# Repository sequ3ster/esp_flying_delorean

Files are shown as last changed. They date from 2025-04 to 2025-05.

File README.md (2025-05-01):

# ESP Flying Delorean

[Circuit](/circuit)<br><br>
[Firmware Installation](/installation)<br><br>
[3D Printing STL](/stl) for EQ LED Mod<br><br>

## Wifi Controller for the Flying DELOREAN V2 Animatronic from Did3D.
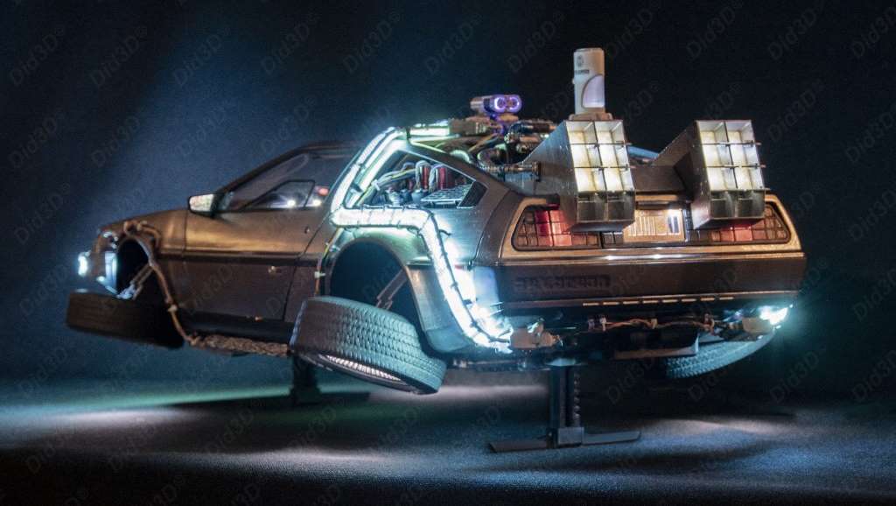
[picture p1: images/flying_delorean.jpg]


<br>[Didier Picard](https://www.did3d.fr) has created an impressive 3D model of a [flying Delorean from Back to the Future Part II](https://www.cgtrader.com/3d-print-models/miniatures/vehicles/flying-delorean-v2-hq-1-8-scale-530mm-3d-print-model).
This model has animatronic and can be controlled via a button on the bottom. The LEDs, servos and sound module are controlled by an Arduino Nano. As there is already a lot to control, all the outputs of the Arduino Nano are used. This leaves no room for expansion.

That's why I thought it would be a good idea to connect an ESP8266 to the Arduino. This way the Delorean can be switched on and off via Wifi and the scenes and moods can also be switched. In addition, there are enough free connections to add the EQ LED mod from the Delorean V1.<br><br>

**Functions**
- Wifi connection with website for control 
- Switching the Delorean on/off
- Changing the scenes
- Changing the mode
- Communication via MQTT (with Home Assistant Discovery Support)
- EQ LED mod for the status indicator<br>

$${\color{red}WARNING!}$$: The car must never be switched on unless it is resting on its wheels in road mode,
otherwise there is a risk of breaking the gears.
This is why the on/off button on the website and the mqtt power switch do not work when the Delorean is flying.
<br><br>

<br><br>**Frontend**
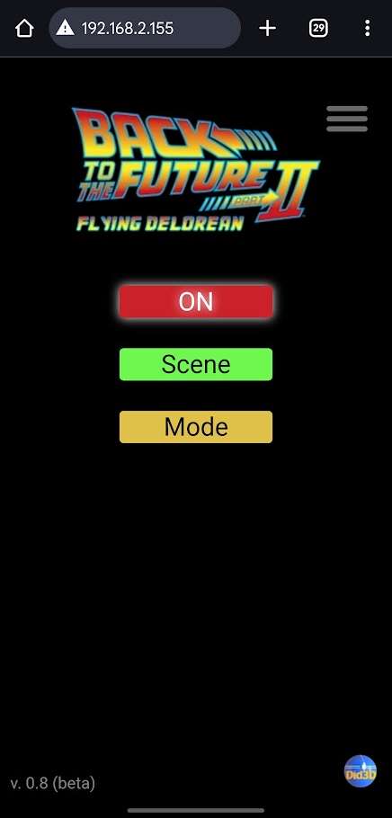
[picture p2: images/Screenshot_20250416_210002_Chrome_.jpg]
<br>
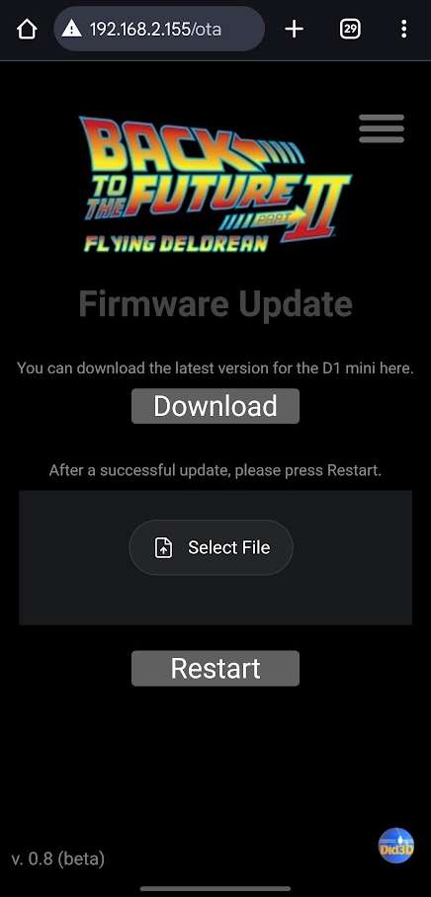
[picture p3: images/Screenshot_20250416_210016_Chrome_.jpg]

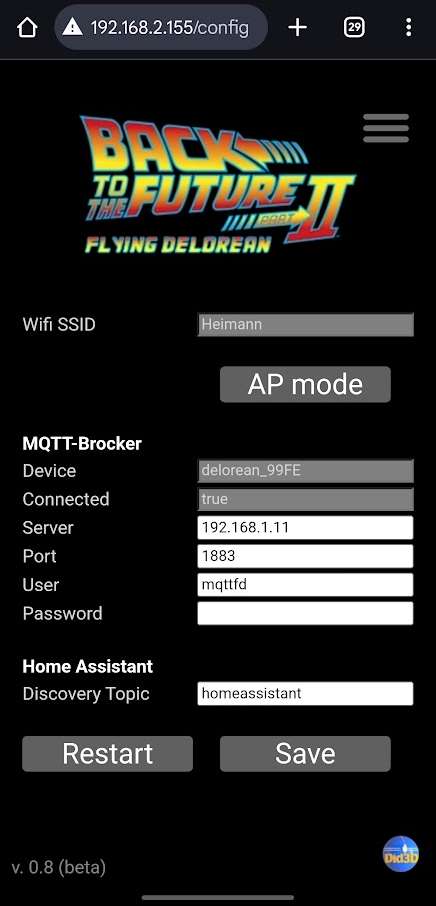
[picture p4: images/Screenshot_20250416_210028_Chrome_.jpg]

<br><br>

**Home Assistant**
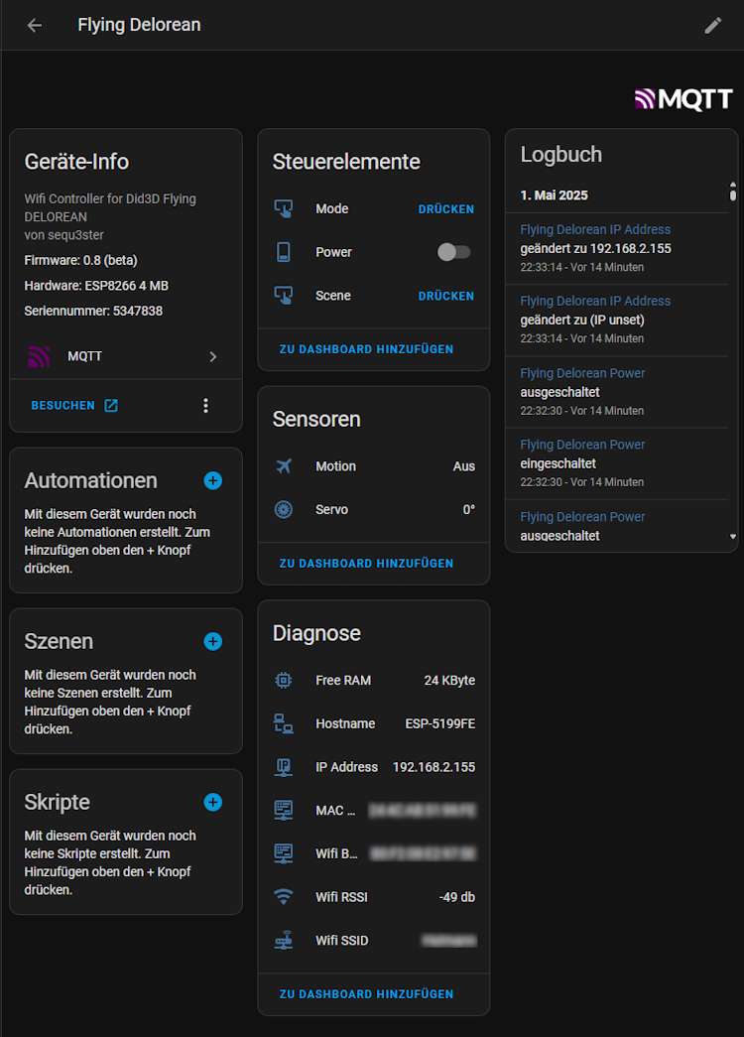
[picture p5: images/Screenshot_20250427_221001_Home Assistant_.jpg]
<br>
<br><br>

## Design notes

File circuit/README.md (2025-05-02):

# Circuit

<table>
  <tr><td><b>Parts</td><td><b>EQ LED Mod</td><td><b>Wifi Mod</td><td><b>Wifi and EQ LED</td></tr>
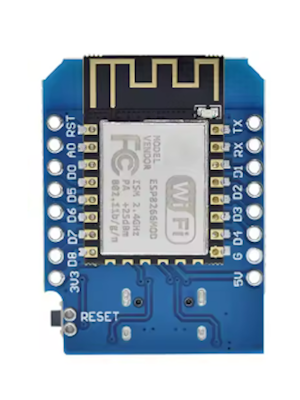
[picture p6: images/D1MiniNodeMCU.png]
  <tr><td><br><a href="https://de.aliexpress.com/item/1005006890254253.html">ES8266 D1 mini (Clone)</a></td><td>$${\color{green}✓}$$</td><td>$${\color{green}✓}$$</td><td>$${\color{green}✓}$$</td></tr>
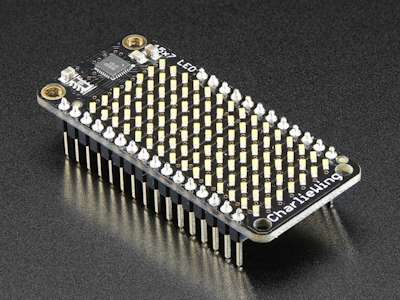
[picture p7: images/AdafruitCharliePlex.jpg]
  <tr><td><br><a href="https://www.berrybase.de/adafruit-15x7-charlieplex-led-matrix-featherwing-warmweiss">Adafruid 15x7 CharliPlex LED Matrix FeatherWing Warm White</a></td><td>$${\color{green}✓}$$</td><td></td><td>$${\color{green}✓}$$</td></tr>
  <tr><td><a href="https://aliexpress.com/item/1005006189547427.html">2x 1k ohm 1/4 watt Resistor</a></td><td></td><td>$${\color{green}✓}$$</td><td>$${\color{green}✓}$$</td></tr>
  <tr><td><a href="https://aliexpress.com/item/1005006189547427.html">2x 10k ohm 1/4 watt Resistor</a></td><td></td><td>$${\color{green}✓}$$</td><td>$${\color{green}✓}$$</td></tr>  
  <tr><td><a href="https://aliexpress.com/item/1005006189547427.html">1x 180k ohm 1/4 watt Resistor</a></td><td></td><td>$${\color{green}✓}$$</td><td>$${\color{green}✓}$$</td></tr>
  <tr><td><a href="https://aliexpress.com/item/1005006189547427.html">1x 220k ohm 1/4 watt Resistor</a></td><td></td><td>$${\color{green}✓}$$</td><td>$${\color{green}✓}$$</td></tr>    
  <tr><td><a href="https://aliexpress.com/item/1005007830470028.html">1x BC547C Transistor</a></td><td></td><td>$${\color{green}✓}$$</td><td>$${\color{green}✓}$$</td></tr>
  <tr><td><a href="https://aliexpress.com/item/33009989924.html">1x IRF9540 Mosfet</a></td><td></td><td>$${\color{green}✓}$$</td><td>$${\color{green}✓}$$</td></tr>
</table>
<br>
  
## EQ LED Mod only

For the EQ LED Mod you only need to connect the Adafruid CharlyPlex to 3.3V, GND, SDA and SCL from the D1 mini. Connect also A0 to 3.3V and RX to Ground. RX to Ground will deactivate Wifi. In that case, the D1 mini will not create an unsafe Access Point for configuration. 
Every time the Deloren is Power on, the CharlyPlex will start the LED Animation for the Status Indicator. This Mod need more room, therefore
you need another Wall-Rear for the Deloren. Also you need anoter EQ-Defusor and EQ-Front.
All STL Files you will find [here](/stl).
<br>$${\color{red}Attention!}$$ Remove RX from Ground for flashing Firmware.
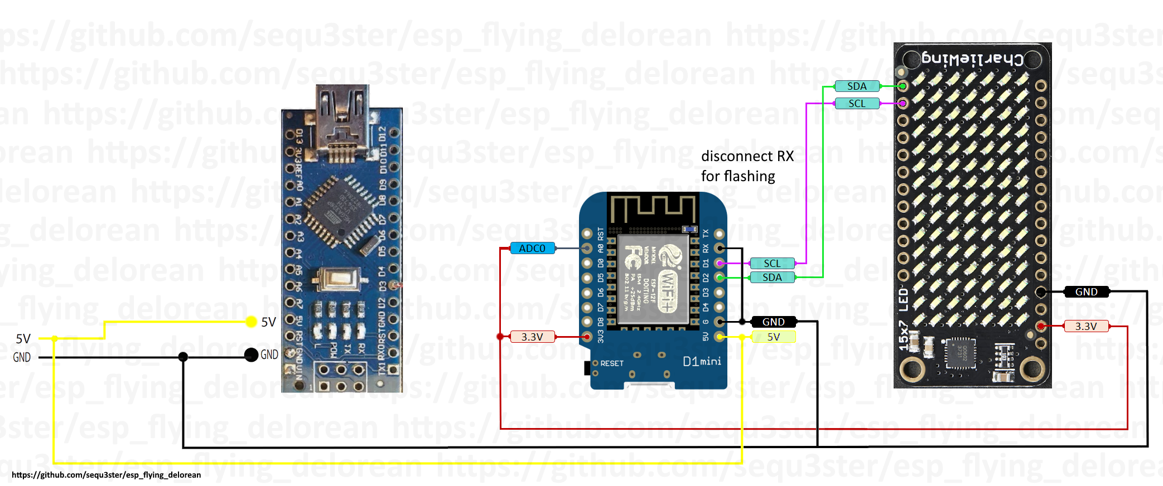
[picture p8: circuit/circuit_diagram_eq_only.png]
<br>
<br><br>

## Wifi Control only

The D1 Mini uses A1 (Ft Servo) to check whether the Delorean is flying. The connection to A6 simulates the push button and there we need a resistor to prevent a short circuit. The IRF9540 interrupts or releases the power to the Arduino. The D1 Mini is also connecte to the Drain from the Mosfet, to detect whether the Delorean is on or off. 
<br>$${\color{red}Attention!}$$ The Arduino uses a different voltage (5V) at the PINs than the D1 Mini (3.3V). Therefore we need another resistors for protection.
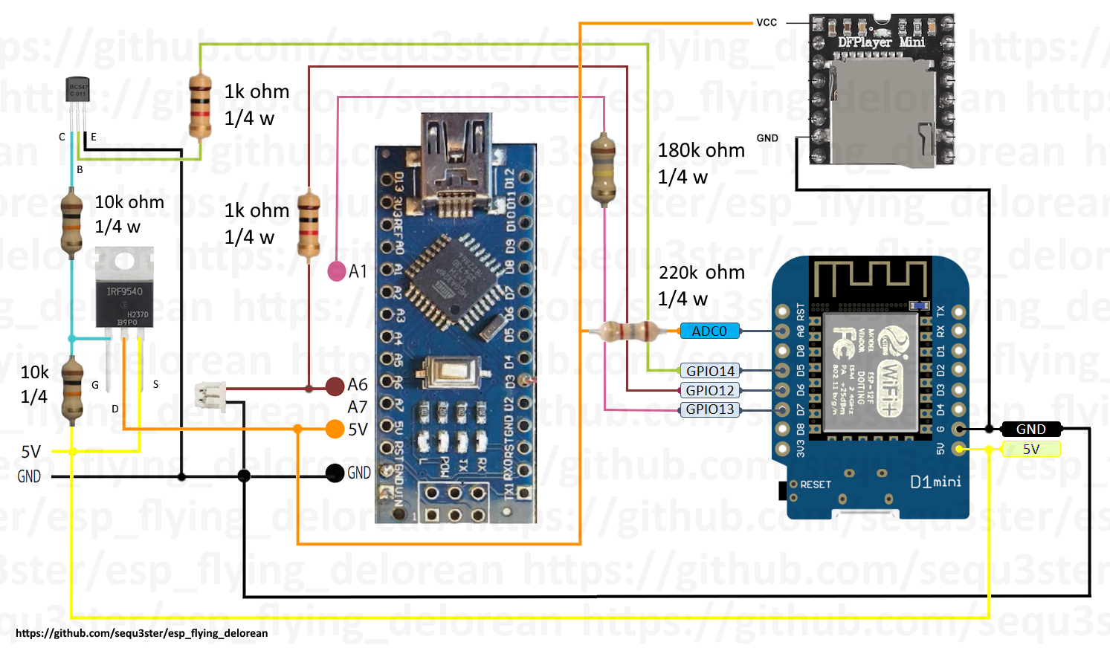
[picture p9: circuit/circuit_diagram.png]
<br>
<br><br>

## Wifi Control with EQ LED Mod

The same as with the two mods above. Except that A0 is not connected to 3.3V, but to the drain of the mosfet. 
<br>$${\color{red}Attention!}$$ RX remains open and is not connected to ground. Because RX to Ground will deactivate Wifi.
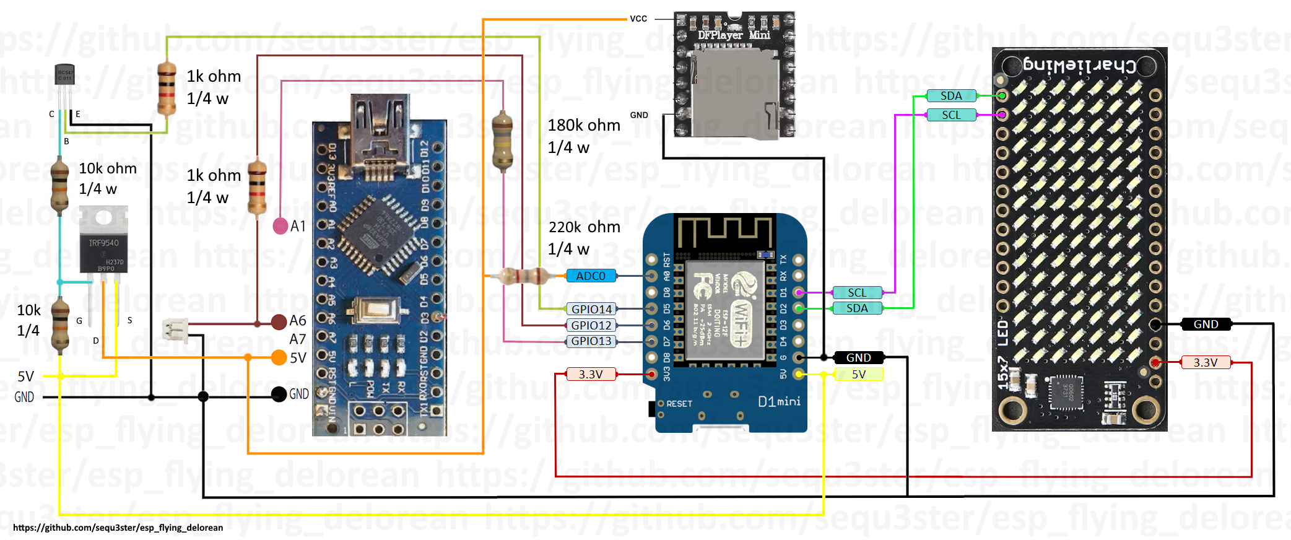
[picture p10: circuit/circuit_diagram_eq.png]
<br>
<br><br>

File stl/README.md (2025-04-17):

## 3D Printing

You need to print the [Wall rear](/stl/Wall_Rear_EQ_version_large_hall_V2.stl), [EQ Front](/stl/EQ-front.stl) and one of the "EQ defuser".  
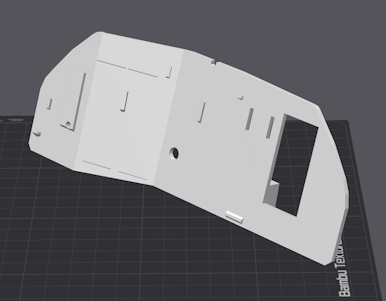
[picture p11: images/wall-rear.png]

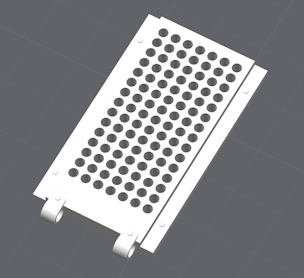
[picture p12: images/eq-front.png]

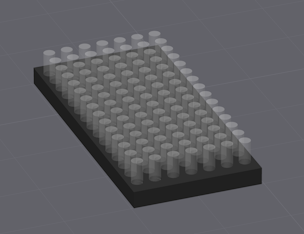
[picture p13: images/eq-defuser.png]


**[EQ-defuser.stl](/stl/EQ-defuser.stl)**<br>
You need to print 7 times this EQ-defuser.
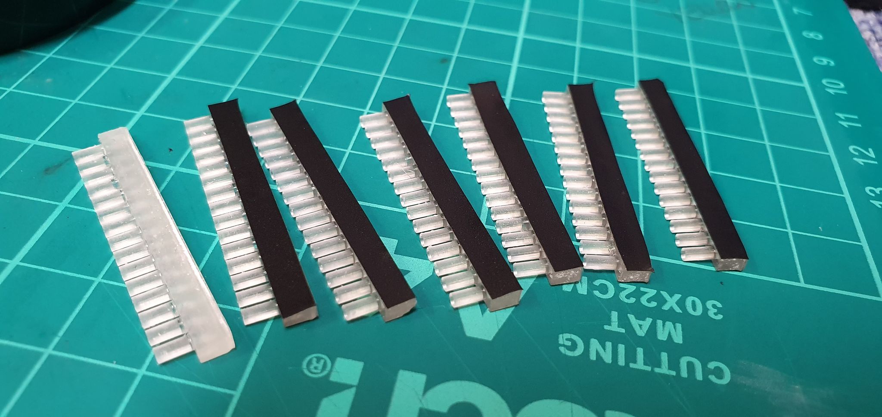
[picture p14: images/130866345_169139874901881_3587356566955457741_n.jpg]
<br>

**[EQ-defuser-ams.stl](/stl/EQ-defuser-ams.stl)**<br>
Or you print this EQ-defuser with a Multicolor FDM Printer like Bambu Lab.
In this version, each LED has its own defuser. These are then separated by a different Filament Color.<br>
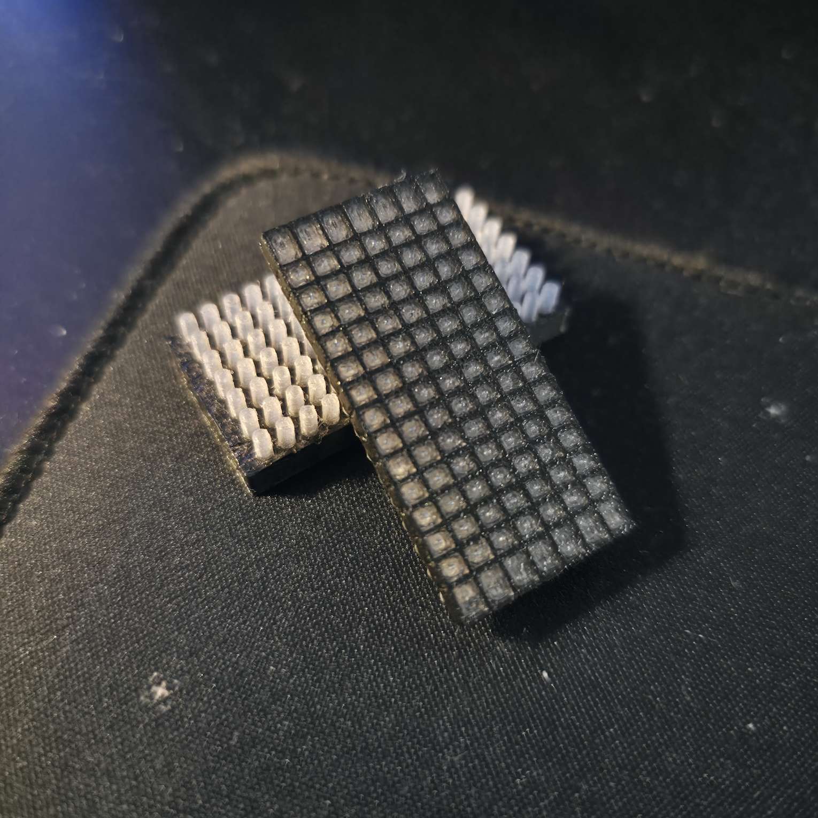
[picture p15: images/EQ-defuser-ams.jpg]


**[EQ-Mod.3mf](/stl/EQ-Mod.3mf) Bambu Studio**<br>
You will also find a Bambu Studio file “EQ-Mod.3mf” with 4 printing plates.
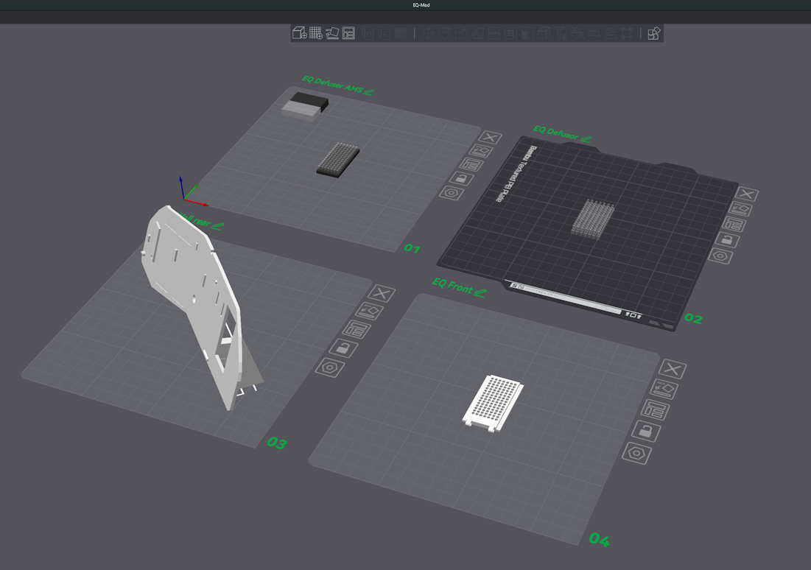
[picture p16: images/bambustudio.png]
<br>

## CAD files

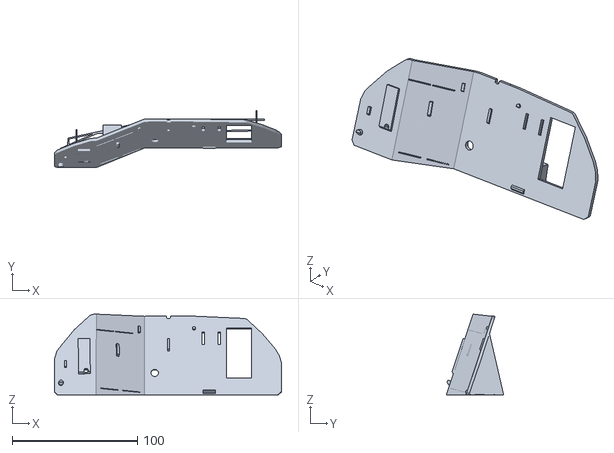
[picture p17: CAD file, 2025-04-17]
stl/Wall_Rear_EQ_version_large_hall_V2.stl
181.4 x 45.8 x 64.6

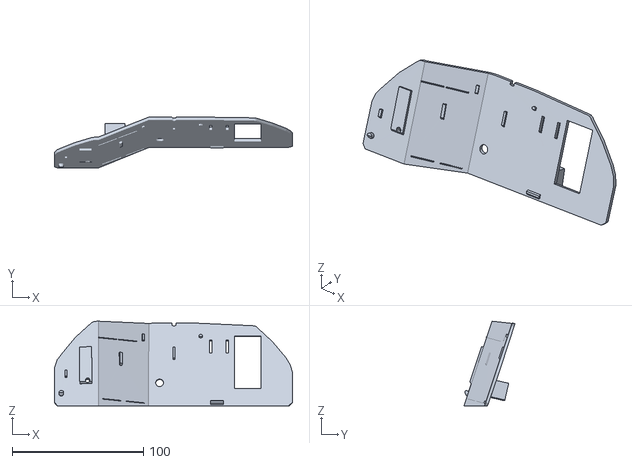
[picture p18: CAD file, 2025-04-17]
stl/Wall_Rear_EQ_version_large_hall_V2_(need support).stl
181.4 x 39.0 x 64.5

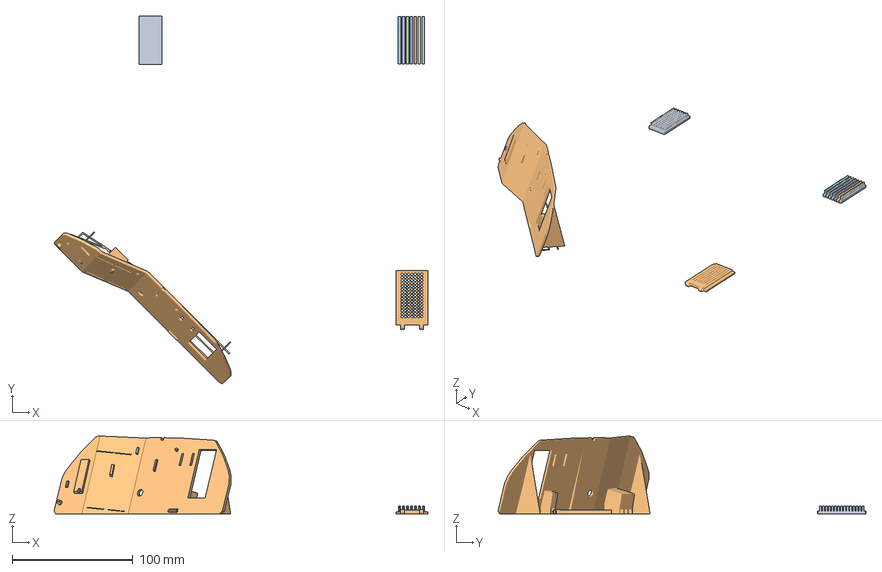
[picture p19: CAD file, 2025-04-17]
stl/EQ-Mod.3mf
309.4 x 304.6 x 64.6 mm
Wall_Rear_EQ_version_large hall_V2 v7.step
Wall_Rear_EQ_version_large hall_V2.stl
EQ-defuser.stl_A x 7
EQ-front.stl

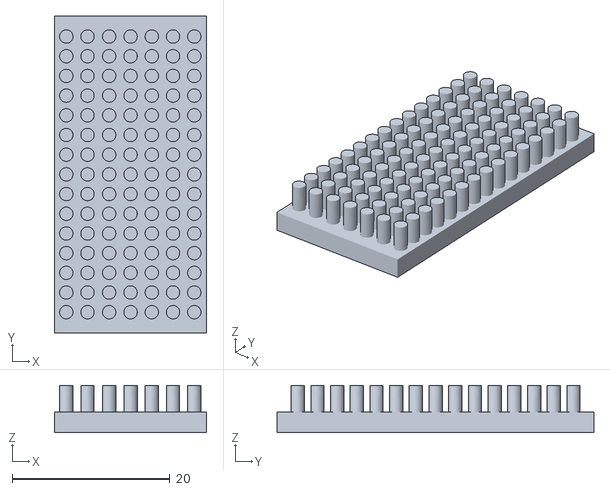
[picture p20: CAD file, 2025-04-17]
stl/EQ-defuser-ams.stl
19.3 x 40.2 x 6.00

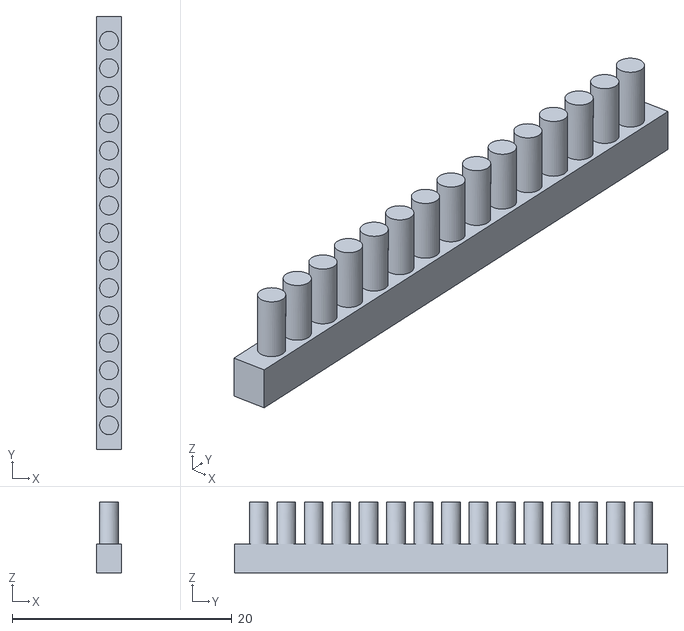
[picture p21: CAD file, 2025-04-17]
stl/EQ-defuser.stl
2.30 x 39.4 x 6.43

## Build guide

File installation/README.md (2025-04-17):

# Firmware Installation

**Firmware**
<br>The [released firmware](https://github.com/sequ3ster/esp_flying_delorean/releases/latest/) is for the D1 Mini (Clone). But maybe it works also for other ESP8266 Boards.
When you like to use another Controller, then feel free to build your own version with the Arduino IDE. Don't forget to upload the Data folder via [Arduino IDE to LittleFS](https://forum.arduino.cc/t/littlefs-data-upload-in-arduino-2-x-x/1174393). 
<br><br>

**Installation D1 Mini**
<br>For the firmware installation I can recommend the online tool from Espressif. [https://espressif.github.io/esptool-js/](https://espressif.github.io/esptool-js/)
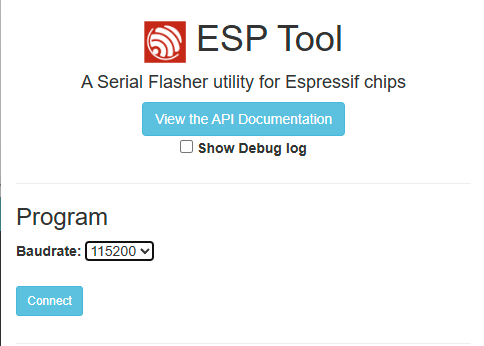
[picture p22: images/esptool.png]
<br><br>
Use 115200 baud, flash address 0x0000 for the [latest firmware](https://github.com/sequ3ster/esp_flying_delorean/releases/latest/esp8266_D1_Mini_EspFlyingDelorean.bin) and flash address 0x200000 for the [littleFS image](https://github.com/sequ3ster/esp_flying_delorean/releases/latest/esp8266_D1_Mini_EspFlyingDelorean.littleFS_0x200000.bin). The littleFS image contains pictures for the web frontend. $${\color{red}Attention!}$$ You only need to flash the littleFS image during the initial installation. Each firmware update can be installed OTA and you do not have to update the littleFS image again. Flashing the littleFS image after installation and configuration will deletes your MQTT configuration.
<table><tr><td><a href="https://github.com/sequ3ster/esp_flying_delorean/releases/latest/esp8266_D1_Mini_EspFlyingDelorean.bin">Firmware 0x0000</a></td>
<td><a href="https://github.com/sequ3ster/esp_flying_delorean/releases/latest/esp8266_D1_Mini_EspFlyingDelorean.littleFS_0x200000.bin">littleFS 0x200000</a></td></tr>
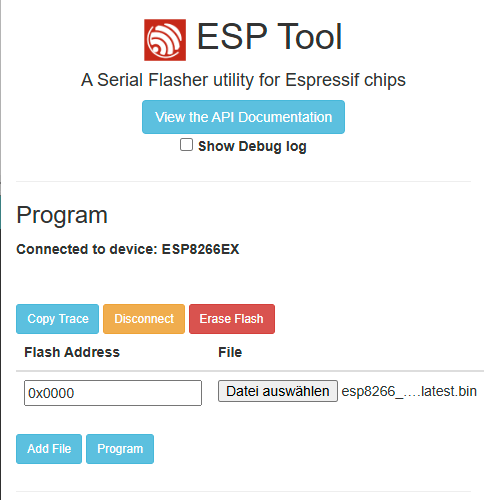
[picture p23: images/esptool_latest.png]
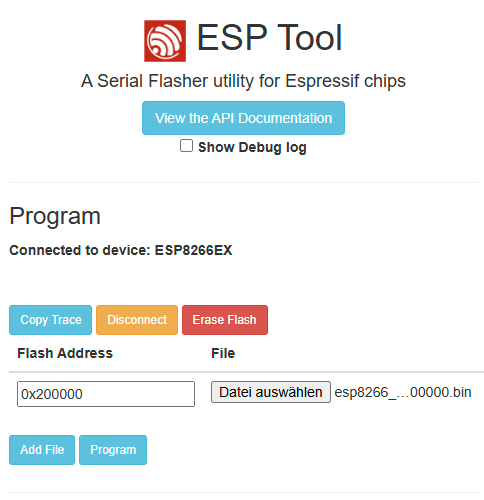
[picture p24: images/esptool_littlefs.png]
<tr><td></td><td></td></tr>
</table>

<br><br>

**Access Point Mode**
<br>When both Images are flashed to the ESP8266, you need to restart the Controller via RST button or power cycle it. Please connect your phone to the Wifi “Flying Delorean”. Then open your browser and go to 192.168.4.1. There you can connect the Wifi Controller to your Wifi network. You can also configure the MQTT Config. Every time you want to change the Wifi settings, you have to go back to AP mode. You will find a button for this in the [configuration menu](/images/Screenshot_20250416_210028_Chrome.jpg).
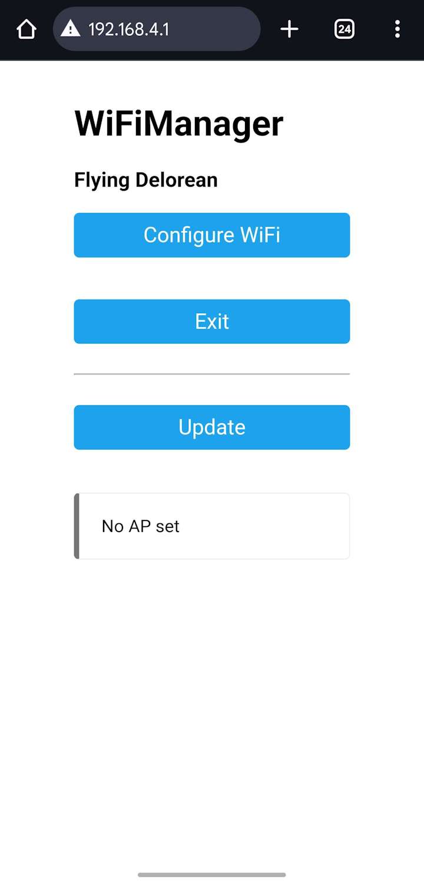
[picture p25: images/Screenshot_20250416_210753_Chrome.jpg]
<br>
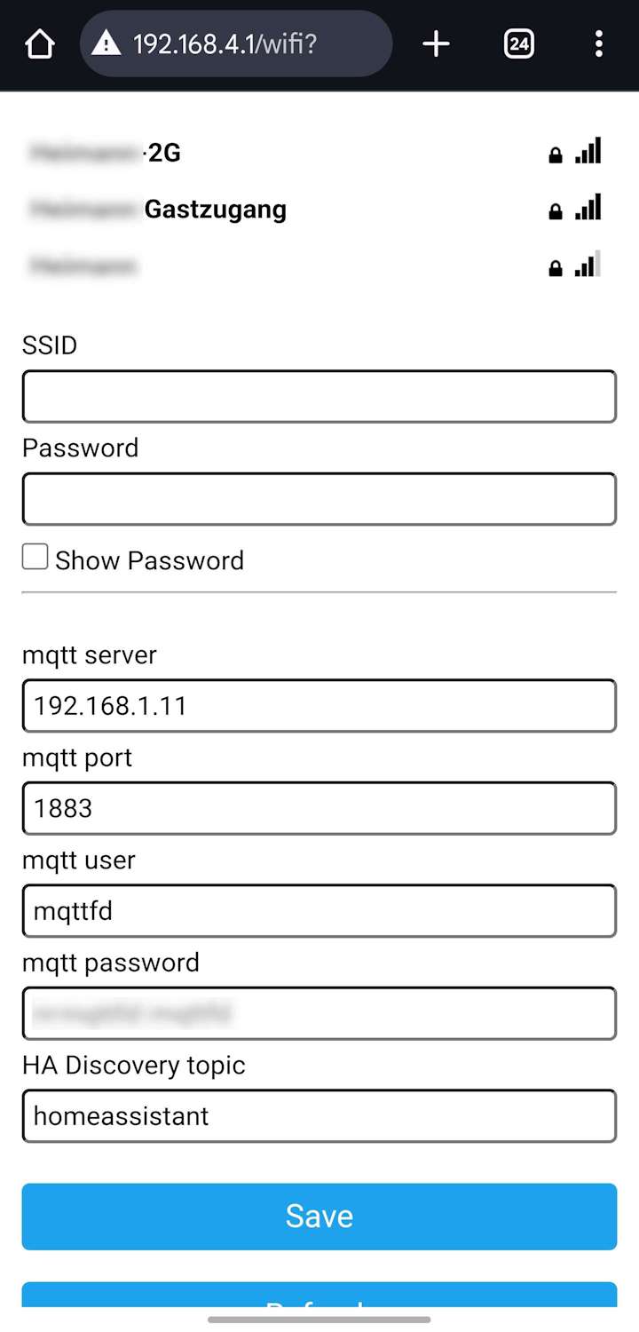
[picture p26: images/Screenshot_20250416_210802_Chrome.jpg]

<br><br>

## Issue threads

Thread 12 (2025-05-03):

Resistor values - Other value for 180k possible?

jrhbcn, 2025-05-03:
First of all, thank you for sharing this project! I am starting building the Delorean and I find this mod an excellent option to improve it!!

I was wondering how tight we must be with the resistor values. I don't have 180k in my kit and planning to use 100k or 220k  instead of the 180k recommended. Would that be fine?

Regards

Edit: sorry, I missed the k in my initial comment!! Edited my issue!

sequ3ster, 2025-05-03:
Thanks for your question.

### **Long story short:**
Yes, you can use a 220K resistor instead of the 180K resistor.

### **Long story:**
The values are all calculated using facts or simplified rules of thumb.
[D1 Mini Schematic V4.0.0[PDF]](https://www.wemos.cc/en/latest/_static/files/sch_d1_mini_v4.0.0.pdf)

**ADC0 (A0)**
ADC0 (A0) only tolerates values in the 0-1V range. That is why it has a built-in voltage divider of R12 220K and R13 100K. This reduces 3.2V to exactly 1V. However, we want to connect 5V here. We therefore connect another 220K resistor in series with R12 and thus obtain R12 440K and R13 100K.

[Vout = (R13 / (R12 + R13)) * Vin](https://en.wikipedia.org/wiki/Voltage_divider)
0.93V = (100K / (440K + 100K)) * 5V

All values above 0.3v are interpreted as switched on by my code. Therefore all resistors from 220K to 680K should work.

**GPIO 13 (D1)**
As you can see on the schematic of the D1 Mini, only the ADC0 has a voltage divider. GPIO 13 (D1) has no voltage divider. However, the PIN can process up to 3.3V according to the manufacturer. But we want to connect 5V. This is where a simplified rule of thumb comes into play. Presumably this only applies to microcontroller circuits.

For every 1 volt reduction, 100K resistance is required.

We want to reduce the 5V by 1.7V to 3.3V. That is 170K according to the rule of thumb. The next one is 180K. If we now apply this to 220K, then we only have 2.8V. However, the ESP8266 still recognizes this as HIGH, as it interprets values between 2.5V and 3.6V as HIGH.

jrhbcn, 2025-05-03:
Perfect, many thanks for your answer @sequ3ster.

Just if someone else is in the same situation, also using some resistors in series (such as 100k + 68k + 12k) should work although it'll be a bit bulky.

Closed 2025-05-03.

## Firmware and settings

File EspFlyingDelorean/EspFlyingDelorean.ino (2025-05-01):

/*********
  Wifi Control for Flying Delorean from Did3d. (https://www.did3d.fr)
  You can buy the 3D Model here: https://www.cgtrader.com/3d-print-models/miniatures/vehicles/flying-delorean-v2-hq-1-8-scale-530mm-3d-print-model
  or here: https://cults3d.com/en/3d-model/art/delorean-volante-v2-hq-1-8-scale-530mm-print-3d

  Benjamin Heimann
  Complete project details at https://github.com/sequ3ster/esp_flying_delorean
  https://www.facebook.com/groups/599517350568861
*********/

#include <FS.h>                   //this needs to be first, or it all crashes and burns...
#include <ESP8266WiFi.h>
#include <ESP8266WebServer.h>
#include <WiFiManager.h>          //https://github.com/tzapu/WiFiManager WiFi Configuration Magic
#include <ArduinoJson.h>          //https://github.com/bblanchon/ArduinoJson
#include <Adafruit_GFX.h>
#include <Adafruit_IS31FL3731.h>
#include <PubSubClient.h>
#include <ElegantOTA.h>
#include "animation.h" 

#ifdef ESP32
  #include <SPIFFS.h>
#endif

// Set web server port number to 80
const unsigned int port = 80;

//define your default values here, if there are different values in config.json, they are overwritten.
char mqtt_server[40];
char mqtt_port[6] = "1883";
char mqtt_user[40];
char mqtt_password[40];
char mqtt_ha_topic[40] = "homeassistant";

// --------------------------------------------------------------
// Please do not change anything from here on
// --------------------------------------------------------------
Adafruit_IS31FL3731_Wing matrix = Adafruit_IS31FL3731_Wing();

ESP8266WebServer server(port);

//flag for saving data
bool shouldSaveConfig = false;

uint8_t MatrixBitmap=1;
uint16_t ServoValue = 0; 
uint16_t LastServoValue = 0; 
int16_t powerstateState = 0;

bool MatrixConnected=false;
bool pushbuttonState = HIGH;
bool poweronoffState = LOW;
bool StatusIndicatorState = HIGH; 
bool DeloreanIsFlying = false; 

unsigned long previousTime = 0; 
unsigned long previousBitmapTime = 0; 
unsigned long TimeOutButton = 0; 
unsigned long startTimeButton = 0; 
unsigned long LastTimeFlying = 0; 
unsigned long timeoutTimeButton = 0;

const char swversion[15] = "0.8 (beta)";

const uint8_t PulseInPin = 13; // ESP8266 PulseIn = D7 --- 180k ohm
const uint8_t pushbutton = 12; //ESP8266 GPIO12 = D6 --- 470-1k ohm
const uint8_t poweronoff = 14; //ESP8266 GPIO14 = D5 --- Mosfet IRL510
const uint8_t powerstate = A0; //ESP8266 ADC0 = A0 --- 180k ohm
const uint8_t StatusIndicator = 2; //ESP8266 GPIO2 = D4
const uint8_t eqModOnly = 3; // ESP8266 GPIO3 = RX --- to Ground if only the EQ mod is required

// --- MQTT Device ---
String mac = WiFi.macAddress(); // Eindeutige Basis für IDs
String deviceId;
String shortcmndTopic;
String longcmndTopic;
String mqttDeviceConfigTopic;
String deviceConfigTopic;
String ipStateTopic;
String motionStateTopic;
String servoStateTopic;
String powerStateTopic;
String powerCommandTopic;
int8_t wifiRssi;
int8_t freeRam;
IPAddress ipAddress;
#define MSG_BUFFER_SIZE	(2432)

WiFiClient espClient;
PubSubClient mqttClient(espClient);
unsigned long lastMsg = 0;
unsigned long lastTryConnect = 0;

//callback notifying us of the need to save config
void saveConfigCallback () {
  Serial.println("Should save config");
  shouldSaveConfig = true;        
}

void SaveConfig () {
  //save the custom parameters to FS
    Serial.println("saving config");
 #if defined(ARDUINOJSON_VERSION_MAJOR) && ARDUINOJSON_VERSION_MAJOR >= 6
    DynamicJsonDocument json(1024);
#else
    DynamicJsonBuffer jsonBuffer;
    JsonObject& json = jsonBuffer.createObject();
#endif
    json["mqtt_server"] = mqtt_server;
    json["mqtt_port"] = mqtt_port;
    json["mqtt_user"] = mqtt_user;
    json["mqtt_password"] = mqtt_password;
    json["mqtt_ha_topic"] = mqtt_ha_topic;
    
    File configFile = SPIFFS.open("/config.json", "w");
    if (!configFile) {
      Serial.println("\033[1;31mfailed to open config file for writing\033[0m");
    }

#if defined(ARDUINOJSON_VERSION_MAJOR) && ARDUINOJSON_VERSION_MAJOR >= 6
    serializeJson(json, Serial);
    serializeJson(json, configFile);
#else
    json.printTo(Serial);
    json.printTo(configFile);
#endif
    configFile.close();
    //end save
}

void setupMosfet() {   
  // IRF9540 datasheet https://www.vishay.com/docs/91078/91078.pdf
  poweronoffState = LOW;    
  pinMode(poweronoff, OUTPUT);
  digitalWrite(poweronoff, poweronoffState);  
}

void setupReadConfig() {
  //read configuration from FS json
  Serial.println("mounting FS...");

  if (SPIFFS.begin()) {
    Serial.println("mounted file system");
    if (SPIFFS.exists("/config.json")) {
      //file exists, reading and loading
      Serial.println("reading config file");
      File configFile = SPIFFS.open("/config.json", "r");
      if (configFile) {
        Serial.println("opened config file");
        size_t size = configFile.size();
        // Allocate a buffer to store contents of the file.
        std::unique_ptr<char[]> buf(new char[size]);

        configFile.readBytes(buf.get(), size);

 #if defined(ARDUINOJSON_VERSION_MAJOR) && ARDUINOJSON_VERSION_MAJOR >= 6
        DynamicJsonDocument json(1024);
        auto deserializeError = deserializeJson(json, buf.get());
        serializeJson(json, Serial);
        if ( ! deserializeError ) {
#else
        DynamicJsonBuffer jsonBuffer;
        JsonObject& json = jsonBuffer.parseObject(buf.get());
        json.printTo(Serial);
        if (json.success()) {
#endif
          Serial.println("\nparsed json");
          strcpy(mqtt_server, json["mqtt_server"]);
          strcpy(mqtt_port, json["mqtt_port"]);
          strcpy(mqtt_ha_topic, json["mqtt_ha_topic"]);
          strcpy(mqtt_user, json["mqtt_user"]);
          strcpy(mqtt_password, json["mqtt_password"]);
          Serial.println("Password: "+String(json["password"]));
        } else {
          Serial.println("\033[1;31mfailed to load json config\033[0m");
        }
        configFile.close();
      }
    }
  } else {
    Serial.println("\033[1;31mfailed to mount FS\033[0m");
  }
  //end read
}

void setupWifi() {  
  // The extra parameters to be configured (can be either global or just in the setup)
  // After connecting, parameter.getValue() will get you the configured value
  // id/name placeholder/prompt default length
  WiFiManagerParameter custom_mqtt_server("server", "mqtt server", mqtt_server, 40);      
  WiFiManagerParameter custom_mqtt_port("port", "mqtt port", mqtt_port, 6);
  WiFiManagerParameter custom_mqtt_user("user", "mqtt user", mqtt_user, 40);
  WiFiManagerParameter custom_mqtt_password("password", "mqtt password", mqtt_password, 40);  
  WiFiManagerParameter custom_mqtt_ha_topic("topic", "HA Discovery topic", mqtt_ha_topic, 40);    

  //WiFiManager
  //Local intialization. Once its business is done, there is no need to keep it around
  WiFiManager wifiManager;
  wifiManager.setSaveConfigCallback(saveConfigCallback);
  wifiManager.setConfigPortalTimeout(180);
  wifiManager.setCustomHeadElement("<style>form[action='/info'],form[action='/exit']:nth-of-type(2){display:none}</style>");
  
  //add all your parameters here
  wifiManager.addParameter(&custom_mqtt_server);
  wifiManager.addParameter(&custom_mqtt_port);
  wifiManager.addParameter(&custom_mqtt_user);
  wifiManager.addParameter(&custom_mqtt_password);   
  wifiManager.addParameter(&custom_mqtt_ha_topic);   

  //fetches ssid and pass and tries to connect
  //if it does not connect it starts an access point with the specified name
  //here  "AutoConnectAP"
  //and goes into a blocking loop awaiting configuration
  if (!wifiManager.autoConnect("Flying Delorean")) {
    Serial.println("\033[1;31mfailed to connect and hit timeout\033[0m");
    delay(3000);
    //reset and try again, or maybe put it to deep sleep
    ESP.restart();
    delay(5000);
  }

  strcpy(mqtt_server, custom_mqtt_server.getValue());
  strcpy(mqtt_port, custom_mqtt_port.getValue());
  strcpy(mqtt_user, custom_mqtt_user.getValue());
  strcpy(mqtt_password, custom_mqtt_password.getValue());  
  strcpy(mqtt_ha_topic, custom_mqtt_ha_topic.getValue());  

  //save the custom parameters to FS
  if (shouldSaveConfig) {
    SaveConfig();
  }
}

void setupWebServer() {  
  // Print local IP address and start web server   
  server.on("/", handle_root);
  server.on("/btn", HTTP_POST, handle_btn);
  server.on("/saveconfig", HTTP_POST, handle_savecfg);
  server.on("/ota", handle_ota);
  server.on("/config", handle_cfg);
  server.on("/apmode", handle_ap);
  server.on("/restart", handle_restart);  
  server.on("/hadiscoveryon", handle_publishHaDiscovery);
  server.on("/hadiscoveryoff", handle_unpublishHaDiscovery);  
  server.on("/powerevents", handle_powerSSE);
  server.on("/longevents", handle_longSSE);
  server.on("/shortevents", handle_shortSSE);
  server.onNotFound(handleWebRequests);
  
  ElegantOTA.begin(&server);

  server.begin();
  Serial.println("\033[1;32mHTTP Server started\033[0m");
}

void setupMqtt() {
  // Init MQTT Client
  mac = WiFi.macAddress(); 
  mac.replace(":", "");
  deviceId = "delorean_" + mac.substring(mac.length() - 4);  
  
  mqttDeviceConfigTopic = String(mqtt_ha_topic) + "/device/" + deviceId + "/config";
  ipStateTopic = "stat/" + deviceId + "/ip";
  motionStateTopic = "stat/" + deviceId + "/motion";
  servoStateTopic = "stat/" + deviceId + "/servo";
  shortcmndTopic = "cmnd/" + deviceId + "/short";
  longcmndTopic = "cmnd/" + deviceId + "/long";
  powerStateTopic = "stat/" + deviceId + "/switch";
  powerCommandTopic = "cmnd/" + deviceId + "/switch";
  
  mqttClient.setServer(mqtt_server, String(mqtt_port).toInt());
  mqttClient.setCallback(mqttCallback);  
  mqttClient.setBufferSize(MSG_BUFFER_SIZE);
}

void setup() {
  Serial.begin(74800);

  setupMosfet();

  pinMode(pushbutton, OUTPUT);
  pinMode(StatusIndicator, OUTPUT);
  pinMode(PulseInPin, INPUT);
  pinMode(powerstate, INPUT);
  pushbuttonState = HIGH;  
  powerstateState = 0;
  StatusIndicatorState = HIGH;
  digitalWrite(pushbutton, pushbuttonState);  
  digitalWrite(StatusIndicator, StatusIndicatorState);

  pinMode(eqModOnly, INPUT_PULLUP);
  if (digitalRead(eqModOnly) == 1) {
    setupReadConfig();
    setupWifi();
    setupMqtt();
    setupWebServer();
  }

  // Check if is something connected to SDA (D4)
  pinMode(D4, OUTPUT);
  digitalWrite(D4, LOW);
  pinMode(D4, INPUT);
  if(!digitalRead(D4)) {
    return;
  }
  
  Serial.println("Connecting Adafruit IS31 CharlieWing");  
  if(! matrix.begin()) {
    Serial.println("\033[1;31mIS31 not found\033[0m");
    return;  
  } else {
    MatrixConnected = true;
    Serial.println("\033[1;32mIS31 Connected\033[0m");
  } 
}

void handle_root() {  
  server.setContentLength(CONTENT_LENGTH_UNKNOWN);
  server.send(200, "text/html", sendHTMLHead());
  server.sendContent(sendHTMLBody());    
  server.sendContent("");
}

void handle_ota() {  
  server.setContentLength(CONTENT_LENGTH_UNKNOWN);
  server.send(200, "text/html", sendHTMLHead());
  server.sendContent(sendHTMLota());    
  server.sendContent("");
}

void PushButton() {
  if ((startTimeButton == 0) && (timeoutTimeButton > 0)) {      
    startTimeButton = millis();
    pushbuttonState = LOW;    
    digitalWrite(pushbutton, pushbuttonState);    
  }  else if (millis() > (startTimeButton + timeoutTimeButton)) {     
    pushbuttonState = HIGH;    
    timeoutTimeButton = 0;
    startTimeButton = 0;
    digitalWrite(pushbutton, pushbuttonState);    
  }
}

uint8_t evaluate_btn_state(String btnState) {
  uint8_t state;
  String lowbtnState = btnState;
  lowbtnState.toLowerCase();
  if (lowbtnState == "off") {
    state = HIGH;
  } else if (lowbtnState == "on") {
    state = LOW;
  } else {
    Serial.println("unknow btn state: "+btnState);
  }  
  return state;
}

void handle_btn() {
  String btnPin = server.arg("btnPin");
  String btnState = server.arg("btnState");
  String powerButton = server.arg("powerbtnState");
  String httpResponse;

  if (!DeloreanIsFlying) {
    if (btnPin == "1") {
      Serial.println("power on/off");    
      if (!DeloreanIsFlying) {
        poweronoffState = evaluate_btn_state(powerButton);
        digitalWrite(poweronoff, poweronoffState);
        httpResponse = "power " ;
        httpResponse += poweronoffState ? "on" : "off";
      }
      publishPowerState();
    } else if (btnPin == "2") {      
      timeoutTimeButton = btnState.toInt();
      Serial.println("press "+String(timeoutTimeButton)+" ms"); 
      PushButton();
      httpResponse = btnState;
    } else {
      Serial.println("btn unknow: "+btnPin);
    }
  }
  server.setContentLength(CONTENT_LENGTH_UNKNOWN);

  if (DeloreanIsFlying) {
    server.send(409, "text/plain", "Conflict: Delorean is flying");
    server.sendContent("");
  } else {
    server.send(200, "text/plain", httpResponse);
    server.sendContent("");
  }  
}

void handle_savecfg() {
  char mqtthatopic[40];
  strcpy(mqtthatopic, server.arg("mqtthatopic").c_str());  

  if (mqtt_ha_topic != mqtthatopic) {
    unpublishHADiscoveryConfig();
    strcpy(mqtt_ha_topic, mqtthatopic);    
  }
  
  strcpy(mqtt_server, server.arg("mqttserver").c_str());
  strcpy(mqtt_port, server.arg("mqttport").c_str());
  strcpy(mqtt_user, server.arg("mqttuser").c_str());
    
  if (server.arg("mqttpass") != "") {
    strcpy(mqtt_password, server.arg("mqttpass").c_str());
  }

  if (server.arg("mqtthatopic") != "") mqttHaDiscoveryConfig();

  SaveConfig();

  server.sendHeader("Location", "/",true);  
  server.send(302, "text/plain", ""); 

  delay(100);
  ESP.restart();
  delay(5000);
}

void handle_ap() {
  server.sendHeader("Location", "http://192.168.4.1/",true);  
  server.send(302, "text/plain", "");
  Serial.println("Start AP Mode");  

  WiFiManager wifiManager;
  wifiManager.resetSettings();  
  delay(200);
  ESP.restart();
  delay(5000);
}

void handle_restart() {
  server.sendHeader("Location", "/",true);  
  server.send(302, "text/plain", "");
  Serial.println("Restart");    
  delay(100);
  ESP.restart();
  delay(5000);
}

void handle_cfg() {
  server.setContentLength(CONTENT_LENGTH_UNKNOWN);
  server.send(200, "text/html", sendHTMLHead());
  server.sendContent(sendConfigHTMLBody());    
  server.sendContent("");  
}

void handle_NotFound() {
  server.send(404, "text/html", sendPageUnknown());
}

void handle_publishHaDiscovery() {
  server.sendHeader("Location", "/",true);  
  server.send(302, "text/plain", "");
  Serial.println("MQTT Home Assistant Discovery Config");

  mqttHaDiscoveryConfig();        
}

void handle_unpublishHaDiscovery() {
  server.sendHeader("Location", "/",true);  
  server.send(302, "text/plain", "");
  Serial.println("MQTT Home Assistatnt Reset Discovery Config");

  unpublishHADiscoveryConfig();        
}

void handle_powerSSE() {
  WiFiClient client = server.client();
  
  if (client) {    
    serverSentEventHeader(client);    
    serverSentPowerEvent(client);      

    // give the web browser time to receive the data
    delay(10); // round about 100 messages per second            
    
    // close the connection:
    client.stop();
  }
}

void handle_longSSE() {
  WiFiClient client = server.client();
  
  if (client) {      
    serverSentEventHeader(client);    
    serverSentLongEvent(client);      

    // give the web browser time to receive the data
    delay(10); // round about 100 messages per second            
    
    // close the connection:
    client.stop();
  }
}

void handle_shortSSE() {
  WiFiClient client = server.client();
  
  if (client) {    
    serverSentEventHeader(client);    
    serverSentShortEvent(client);      

    // give the web browser time to receive the data
    delay(10); // round about 100 messages per second            
    
    // close the connection:
    client.stop();
  }
}

void serverSentEventHeader(WiFiClient client) {
  client.println("HTTP/1.1 200 OK");
  client.println("Content-Type: text/event-stream");
  client.println("Cache-Control: no-cache");  // refresh the page automatically every 5 sec
  client.println("Connection: close");  // the connection will be closed after completion of the response
  client.println();
}

void serverSentPowerEvent(WiFiClient client) {
  String Output = "data: " + String(poweronoffState ? "ON" : "OFF");
  client.println(Output);
  client.println();
}

void serverSentLongEvent(WiFiClient client) {  
  String Output;
  if ((timeoutTimeButton > 3000) && (!pushbuttonState)){
    Output = "data: ON";
  } else {
    Output = "data: OFF";
  }
  client.println(Output);
  client.println();
}

void serverSentShortEvent(WiFiClient client) {
  String Output;
  if ((timeoutTimeButton < 3000) && (!pushbuttonState)){
    Output = "data: ON";
  } else {
    Output = "data: OFF";
  }
  client.println(Output);
  client.println();
}

String sendPageUnknown() {
    String ptr = "<!DOCTYPE html> <html>\n";
  
  ptr += "<head>";
  ptr += "<meta name=\"viewport\" content=\"width=device-width, initial-scale=1.0, user-scalable=no\">\n";
  ptr += "<title>Page unknown</title>\n";
  ptr += "</head>\n";
  ptr += "<body>\n";
  ptr += "<h1>Page unknown</h1>\n";
  ptr += "<a href=\"/\">Return to main page</a>\n";
  ptr += "</body>\n";
  ptr += "</html>\n";
  return ptr;
}

void handleWebRequests(){
  if(loadFromSpiffs(server.uri())) return;
  String message = "File Not Detected\n\n";
  message += "URI: ";
  message += server.uri();
  message += "\nMethod: ";
  message += (server.method() == HTTP_GET)?"GET":"POST";
  message += "\nArguments: ";
  message += server.args();
  message += "\n";
  for (uint8_t i=0; i<server.args(); i++){
    message += " NAME:"+server.argName(i) + "\n VALUE:" + server.arg(i) + "\n";
  }
  server.send(404, "text/plain", message);
  Serial.println(message);
}

bool loadFromSpiffs(String path){
  String dataType = "text/plain"; 
  if(path.endsWith("/")) path += "index.htm";
 
  if(path.endsWith(".src")) path = path.substring(0, path.lastIndexOf("."));
  else if(path.endsWith(".html")) dataType = "text/html";
  else if(path.endsWith(".htm")) dataType = "text/html";
  else if(path.endsWith(".css")) dataType = "text/css";
  else if(path.endsWith(".js")) dataType = "application/javascript";
  else if(path.endsWith(".png")) dataType = "image/png";
  else if(path.endsWith(".gif")) dataType = "image/gif";
  else if(path.endsWith(".jpg")) dataType = "image/jpeg";
  else if(path.endsWith(".ico")) dataType = "image/x-icon";
  else if(path.endsWith(".webp")) dataType = "image/webp";
  else if(path.endsWith(".xml")) dataType = "text/xml";
  else if(path.endsWith(".pdf")) dataType = "application/pdf";
  else if(path.endsWith(".zip")) dataType = "application/zip";
  
  File dataFile = SPIFFS.open(path.c_str(), "r");
  if (server.hasArg("download")) dataType = "application/octet-stream";
  if (server.streamFile(dataFile, dataType) != dataFile.size()) {
  }
  
  dataFile.close();
  return true;
}

String build_btn_form(String btnPin, uint8_t btnState) {
  String ptr = "<form action=\"btn\" method=\"post\" id=\"powerForm\">\n";
  String btnStateStr = String(btnState ? "ON" : "OFF");  
  String lowbtnStateStr = btnStateStr;  
  lowbtnStateStr.toLowerCase();

  ptr += "  <input type=\"hidden\" name=\"btnPin\" value=\""+btnPin+"\">\n";
  ptr += "  <input type=\"hidden\" name=\"powerbtnState\" id=\"powerbtnState\" value=\""+btnStateStr+"\">\n";
  ptr += "  <input type=\"submit\" id=\"powerButton\" class=\"button button-" + lowbtnStateStr + "\" value=\"" + btnStateStr + "\">\n";

  ptr += "</form>\n";
  ptr += "<script type=\"text/javascript\">"; 
  ptr += "  const powerButton = document.getElementById('powerButton');";    
  ptr += "  document.addEventListener('DOMContentLoaded', function() {";
  ptr += "    const powerForm = document.getElementById('powerForm');"; 
  ptr += "    powerForm.addEventListener('submit', function(event) {";
  ptr += "      event.preventDefault();"; 
  ptr += "      const formData = new FormData(powerForm);"; 
  ptr += "      fetch('/btn', {"; 
  ptr += "        method: 'POST',"; 
  ptr += "        body: formData,"; 
  ptr += "      })";
  ptr += "      .then(response => {";
  ptr += "        if (!response.ok) {";
  ptr += "          throw new Error(`HTTP error! status: ${response.status}`);";
  ptr += "        }";
  ptr += "        return response.text();"; 
  ptr += "      })";
  ptr += "      .then(data => {";
  ptr += "        console.log('Success:', data);";
  ptr += "        if (powerButton.value == 'OFF') { powerButton.style.color = 'white'; powerButton.className = \"button button-on\"; powerbtnState.value = 'ON'; powerButton.value = 'ON'; }";
  ptr += "        else { powerButton.style.color = 'black'; powerButton.className = \"button button-off\"; powerbtnState.value = 'OFF'; powerButton.value = 'OFF'; }";  
  ptr += "      })";
  ptr += "      .catch(error => {";
  ptr += "        console.error('Error on seding formular:', error);";
  ptr += "        powerButton.style.color = 'black'; powerButton.className = \"button button-off\"; powerbtnState.value = 'OFF'; powerButton.value = 'OFF';";
  ptr += "      });";
  ptr += "    });";
  ptr += "  });";
  ptr += "  const powerEventSource = new EventSource('/powerevents');";  
  ptr += "  powerEventSource.onmessage = function(event) { ";
  ptr += "    const powerbtnState = document.getElementById('powerbtnState');";
  ptr += "    powerButton.value = event.data;";  
  ptr += "    if (event.data == 'ON') { powerButton.style.color = 'white'; powerButton.className = \"button button-on\"; powerbtnState.value = event.data;}";
  ptr += "    else { powerButton.style.color = 'black'; powerButton.className = \"button button-off\"; powerbtnState.value = event.data; }";  
  ptr += "  }";    
  ptr += "</script>";
  return ptr;
}
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
void loop() {    
  if (digitalRead(eqModOnly) == 1) {
    CheckInputs();  
    server.handleClient();      
    PushButton();
    mqttloop();  
  }
  matrixloop();  
}

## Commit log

2025-04-06 MQTT Power - SSE for Power Button
2025-04-17 Added STLs
    [EQ-Mod.3mf, EQ-defuser-ams.stl, EQ-defuser.stl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]
2025-04-17 Rename Wall_Rear_EQ_version_large hall_V2 (need support).stl to Wall_Rear_EQ_version_large_hall_V2_(need support).stl
    [Wall_Rear_EQ_version_large_hall_V2_(need support).stl]
2025-04-17 Rename Wall_Rear_EQ_version_large hall_V2.stl to Wall_Rear_EQ_version_large_hall_V2.stl
    [Wall_Rear_EQ_version_large_hall_V2.stl]
2025-04-25 Update Circuit
2025-04-26 Changed mosfet from N-Channel to P-Channel
2025-04-28 DPlayer added to circuit
2025-04-28 Updated Manuel for HA and Circuit
2025-04-28 Added Only EQ LED Mod
